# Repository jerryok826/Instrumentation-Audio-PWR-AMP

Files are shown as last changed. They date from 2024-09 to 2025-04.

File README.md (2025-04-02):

# Instrumentation-Audio-PWR-AMP

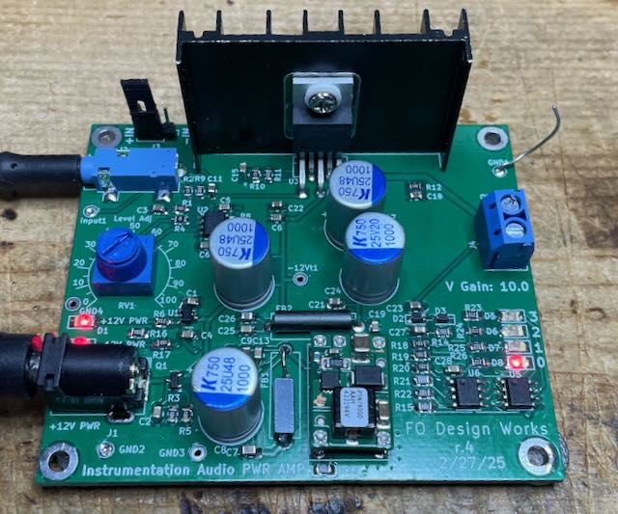
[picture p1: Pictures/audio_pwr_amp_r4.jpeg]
Robot_Front


## Project Description
I needed a audio amp I could use to test speakers and haptics. Most audio amps today seem to be class D using some form of PWM output drive. These cannot be easily be tested with a scope. So I started looking for a linear class AB audio amp. The old LM1875 meets these requirements. The other specs I was looking for were running from 12 volts. Also DC direct speaker dirve so the amp's low frequency performance was the very best.  Also I wanted a calibrated gain. With the audio attenuation pot set to 100% the input to out gain is 20. The design uses a on board 12 volt to -12v converter to generated the required negative supply voltage for the LM1875. The DC offset at the speaker terminals is typically about 1 millvolt. I call this board a "Instrumentation Audio PWR AMP" because it has known characteristicss for testing speakers and haptics. ALso the polarity of the output can be changed via a jump. Also there is a small VU meter to monitor the speaker driver level. This is mostly for debugging the a haptics test setup.

The unit should put out about 10 watts into a 4 ohm speaker. The spec sheet for the LM1875 is in the Docs directory. 

### Project Status
The project is basically complete.

## Design Files
This project was designed with Kicad 7.X

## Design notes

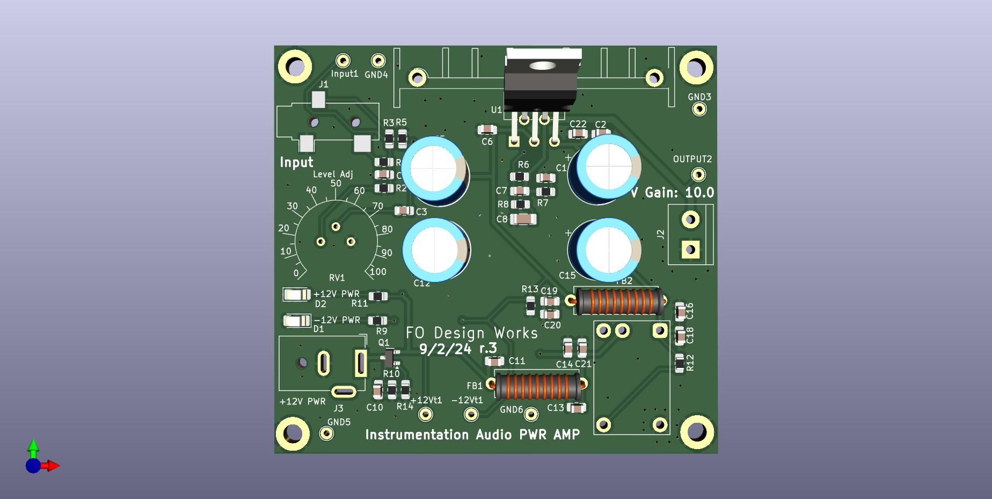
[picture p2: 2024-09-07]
Hardware/Kicad/audio_pwr_amp_r3.jpg

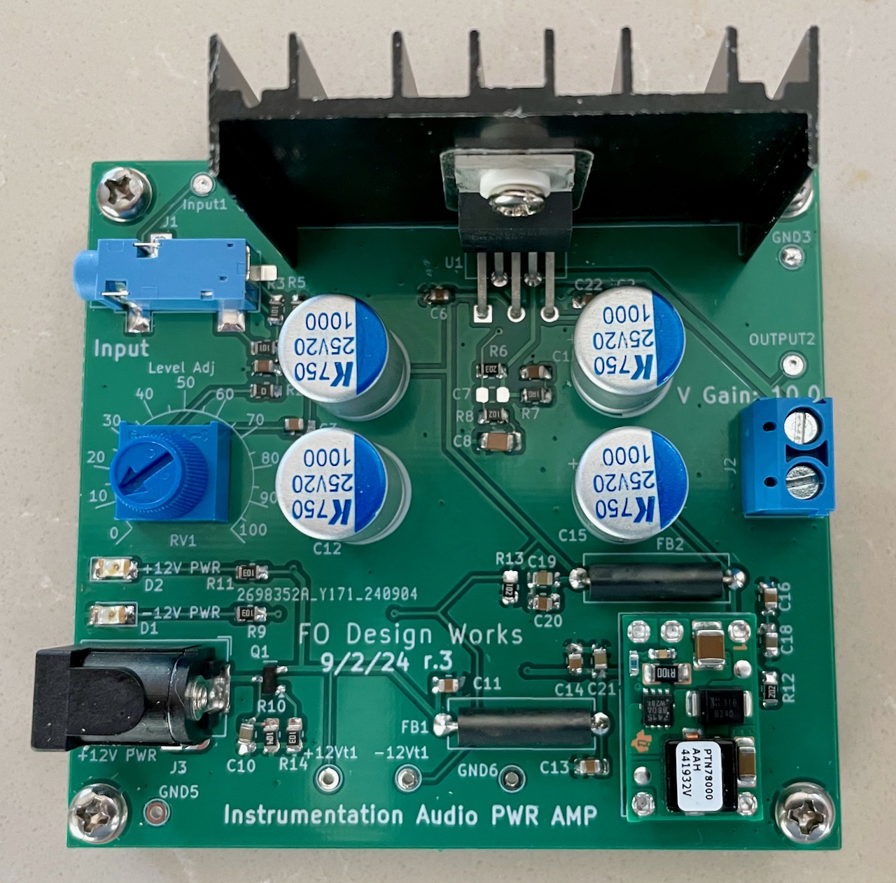
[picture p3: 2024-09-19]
Pictures/audio_pwr_amp_r3.jpeg

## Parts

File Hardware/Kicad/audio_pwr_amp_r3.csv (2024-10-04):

Source: | /home/jerryo/kicad/audio_pwr_amp/audio_pwr_amp_r3/audio_pwr_amp_r3.kicad_sch
Date: | Fri 04 Oct 2024 04:06:32 PM PDT
Tool: | Eeschema 7.0.11-7.0.11~ubuntu22.04.1
Generator: | /usr/share/kicad/plugins/bom_csv_grouped_by_value.py
Component Count: | 43
Collated Components:
Item | Qty | Reference(s) | Value | LibPart | Footprint | Datasheet | DNP | Description | Vendor | Vendor Part#
1 | 4 | C1, C5, C12, C15 | 1000uF | Device:C_Polarized_Small_US | Capacitor_THT:CP_Radial_D10.0mm_P5.00mm | ~ |  | CAP ALUM POLY 1000UF 20% 25V TH | Digikey | 399-A750MV108M1EAAE014-ND
2 | 5 | C2, C3, C6, C16, C17 | 10uF | Device:C_Small | Capacitor_SMD:C_0805_2012Metric_Pad1.18x1.45mm_HandSolder | ~ |  | CAP CER, 10uF, 25V, X7R, 0805 | Digikey | 1276-6454-1-ND
3 | 1 | C4 | 10nF | Device:C_Small | Capacitor_SMD:C_0805_2012Metric_Pad1.18x1.45mm_HandSolder | ~ |  | CAP CER, 10nF, 25V, X7R, 0805 | Digikey | 399-14402-1-ND
4 | 1 | C8 | 22uF | Device:C_Small | Capacitor_SMD:C_0805_2012Metric_Pad1.18x1.45mm_HandSolder | ~ |  | CAP CER 22UF 25V X5R 0805 | Digikey | 1276-CL21A226MAYNNNECT-ND
5 | 1 | C9 | 0.22uF | Device:C_Small | Capacitor_SMD:C_0805_2012Metric_Pad1.18x1.45mm_HandSolder | ~ |  | CAP CER, 0.22uF, 25V, X7R, 1206 | Digikey | 1276-1161-1-ND
6 | 5 | C10, C18, C19, C21, C22 | 0.1uF | Device:C_Small | Capacitor_SMD:C_0805_2012Metric_Pad1.18x1.45mm_HandSolder | ~ |  | CAP CER, 0.1uF, 25V, X7R, 0805 | Digikey | 1276-1099-1-ND
7 | 3 | C11, C13, C14 | 4.7uF | Device:C_Small | Capacitor_SMD:C_0805_2012Metric_Pad1.18x1.45mm_HandSolder | ~ |  | CAP CER, 4.7uF, 25V, X7R, 0805 | Digikey | 1276-1244-1-ND
8 | 2 | D1, D2 | RED_LED | Device:LED | LED_SMD:LED_1206_3216Metric_Pad1.42x1.75mm_HandSolder | https://sunledusa.com/products/spec/XZM2CRK55W-3.pdf |  | LED RED CLEAR SMD 1206 | Digikey | 1497-XZM2CRK55W-3RTCT-ND
9 | 2 | FB1, FB2 | FERRITE CORE SOLID 1.30MM | Device:FerriteBead_Small | Inductor_THT:L_Axial_L14.0mm_D4.5mm_P15.24mm_Horizontal_Fastron_LACC | https://www.fair-rite.com/wp-content/uploads/2019/12/2673000701cat.pdf |  | FERRITE CORE SOLID 1.30MM | Digikey | 1934-1292-ND
10 | 1 | HS1 | Heatsink_Pad_2Pin | Mechanical:Heatsink_Pad_2Pin | jerrys_Library:Heatsink_Audio_Amp | ~
11 | 1 | J1 | Audio In | audio_connector:AudioJack3 | Connector_Audio:Jack_3.5mm_CUI_SJ-3523-SMT_Horizontal |  |  | CONN JACK STEREO 3.5MM SMD R/A | Digikey | CP-3524SJBECT-ND
12 | 1 | Q1 | DMG2301L | Transistor_FET:DMG2301L | Package_TO_SOT_SMD:SOT-23 | https://www.diodes.com/assets/Datasheets/DMG2301L.pdf |  | MOSFET P-CH 20V 3A SOT23 | Digikey | DMG2301L-7DICT-ND
13 | 2 | R1, R3 | 100R | Device:R_Small_US | Resistor_SMD:R_0805_2012Metric_Pad1.20x1.40mm_HandSolder | ~ |  | RES 100 OHM 1% 1/8W 0805 | Digikey | RMCF0805FT100RCT-ND
14 | 1 | R2 | 0R | Device:R_Small_US | Resistor_SMD:R_0805_2012Metric_Pad1.20x1.40mm_HandSolder | ~ |  | RES 0 OHM JUMPER 1/8W 0805 | Digikey | 311-0.0ARCT-ND
15 | 2 | R5, R6 | 20K | Device:R_Small_US | Resistor_SMD:R_0805_2012Metric_Pad1.20x1.40mm_HandSolder | ~ |  | RES 20K OHM %1 1/10W 0805 SMD | Digikey | P20KDACT-ND
16 | 1 | R7 | 1R | Device:R_Small_US | Resistor_SMD:R_0805_2012Metric_Pad1.20x1.40mm_HandSolder | ~ |  | RES SMD 1 OHM 1% 1/2W 0805 | Digikey | 541-1.00TCT-ND
17 | 2 | R8, R13 | 1K | Device:R_Small_US | Resistor_SMD:R_0805_2012Metric_Pad1.20x1.40mm_HandSolder | ~ |  | RES 1K OHM %1 1/10W 0805 SMD | Digikey | 311-1.00KCRCT-ND
18 | 3 | R9, R11, R14 | 10K | Device:R_Small_US | Resistor_SMD:R_0805_2012Metric_Pad1.20x1.40mm_HandSolder | ~ |  | RES 10K OHM %1 1/10W 0805 SMD | Digikey | 311-10.0KCRCT-ND
19 | 1 | R10 | 100K | Device:R_Small_US | Resistor_SMD:R_0805_2012Metric_Pad1.20x1.40mm_HandSolder | ~ |  | RES 100K OHM 1% 1/8W 0805 | Digikey | 311-100KCRCT-ND
20 | 1 | R12 | 2K | Device:R_Small_US | Resistor_SMD:R_0805_2012Metric_Pad1.20x1.40mm_HandSolder | ~ |  | RES SMD 2K OHM 1% 1/8W 0805 | Digikey | P2.00KCCT-ND
21 | 1 | RV1 | 1k | Device:R_Potentiometer_US | jerrys_Library:Potentiometer_Bourns_3386P_Vertical | https://www.bourns.com/docs/Product-Datasheets/3386.pdf |  | TRIMMER 1K OHM 0.5W PC PIN TOP | Digikey | 3386F-1-102TLF-ND
22 | 1 | U1 | LM1875 | Amplifier_Audio:LM1875 | Package_TO_SOT_THT:TO-220-5_P3.4x3.7mm_StaggerOdd_Lead3.8mm_Vertical | http://www.ti.com/lit/ds/symlink/lm1875.pdf |  | IC AMP CLASS AB MONO 25W TO220-5 | Digikey | LM1875T/NOPB-ND
23 | 1 | U2 | PTN78000AAH | jerrys_Library:PTN78000A | Module:Texas_EUS_R-PDSS-T5_THT | https://www.ti.com/lit/ds/symlink/ptn78000a.pdf |  | DC DC CONVERTER -15 TO -3V | Digikey | 296-20501-ND

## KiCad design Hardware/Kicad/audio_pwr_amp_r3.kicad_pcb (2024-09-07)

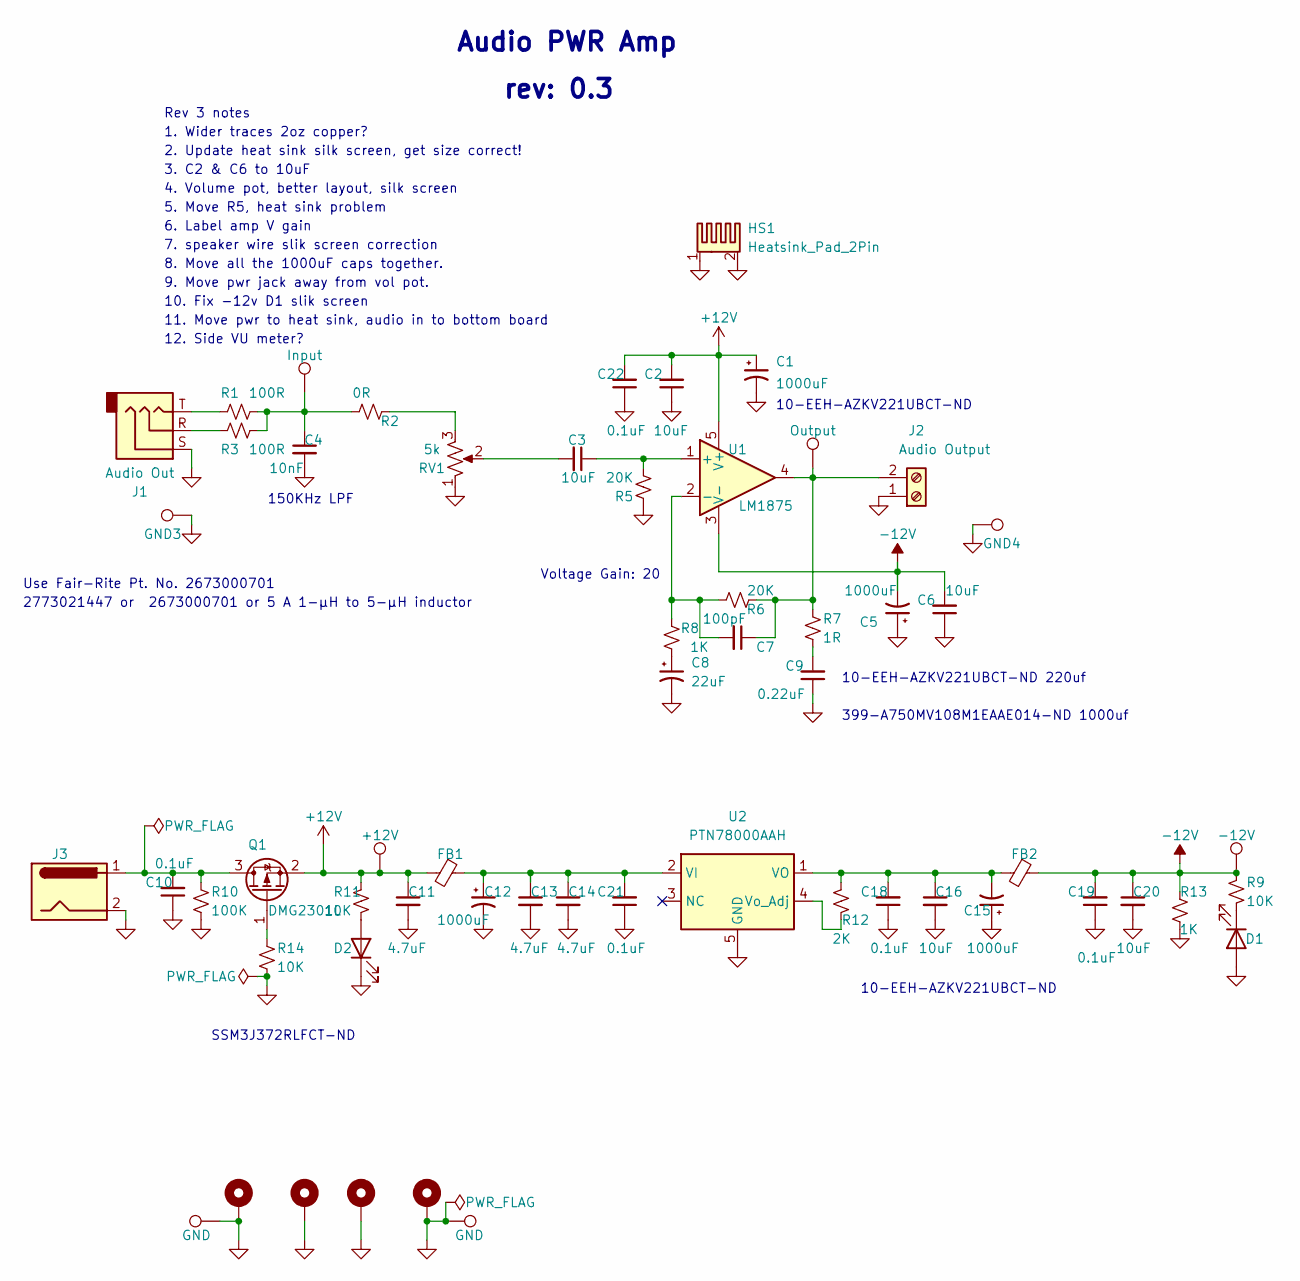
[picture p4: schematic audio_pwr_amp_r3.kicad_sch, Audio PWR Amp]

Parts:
+12Vt1: +12V; TestPoint_THTPad_D2.0mm_Drill1.0mm
-12Vt1: -12V; TestPoint_THTPad_D2.0mm_Drill1.0mm
C1, C5, C12, C15: 1000uF; CP_Radial_D10.0mm_P5.00mm
C2, C3, C6, C16, C20: 10uF; C_0805_2012Metric_Pad1.18x1.45mm_HandSolder
C4: 10nF; C_0805_2012Metric_Pad1.18x1.45mm_HandSolder
C7: 100pF; C_0805_2012Metric_Pad1.18x1.45mm_HandSolder
C8: 22uF; C_1206_3216Metric_Pad1.33x1.80mm_HandSolder
C9: 0.22uF; C_0805_2012Metric_Pad1.18x1.45mm_HandSolder
C10, C18, C19, C21, C22: 0.1uF; C_0805_2012Metric_Pad1.18x1.45mm_HandSolder
C11, C13, C14: 4.7uF; C_0805_2012Metric_Pad1.18x1.45mm_HandSolder
D1, D2: OC_Fault; LED_1206_3216Metric_Pad1.42x1.75mm_HandSolder
FB1, FB2: FerriteBead, 6A 1 9mΩ 33Ω@100MHz ±25% 1206 Ferrit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; L_Axial_L14.0mm_D4.5mm_P15.24mm_Horizontal_Fastron_LACC
GND3, GND4: TP_FET_Drive; TestPoint_THTPad_D2.0mm_Drill1.0mm
GND5, GND6: GND; TestPoint_THTPad_D2.0mm_Drill1.0mm
H1, H2, H3, H4: MountingHole_Pad; MountingHole_3.2mm_M3_ISO7380_Pad_TopBottom
HS1: Heatsink_Pad_2Pin; Heatsink_Audio_Amp
Input1: Input; TestPoint_THTPad_D2.0mm_Drill1.0mm
J1: Audio Out; Jack_3.5mm_CUI_SJ-3523-SMT_Horizontal
J2: Audio Output; TerminalBlock_bornier-2_P5.08mm; LCSC No Stock
J3: INPUT_PWR; BarrelJack_GCT_DCJ200-10-A_Horizontal
OUTPUT2: Output; TestPoint_THTPad_D2.0mm_Drill1.0mm
Q1: DMG2301L; SOT-23
R1, R3: 100R; R_0805_2012Metric_Pad1.20x1.40mm_HandSolder
R2: 0R; R_0805_2012Metric_Pad1.20x1.40mm_HandSolder
R5, R6: 20K; R_0805_2012Metric_Pad1.20x1.40mm_HandSolder
R7: 1R; R_0805_2012Metric_Pad1.20x1.40mm_HandSolder
R8, R13: 1K; R_0805_2012Metric_Pad1.20x1.40mm_HandSolder
R9, R11, R14: 10K; R_0805_2012Metric_Pad1.20x1.40mm_HandSolder
R10: 100K; R_0805_2012Metric_Pad1.20x1.40mm_HandSolder
R12: 2K; R_0805_2012Metric_Pad1.20x1.40mm_HandSolder
RV1: 5k; Potentiometer_Bourns_3386P_Vertical
U1: LM1875; TO-220-5_P3.4x3.7mm_StaggerOdd_Lead3.8mm_Vertical
U2: PTN78000AAH; Texas_EUS_R-PDSS-T5_THT

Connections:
+12V: +12Vt1.1, C1.1, C2.2, C11.1, C22.2, FB1.2, Q1.2 (S), R11.2, U1.5 (V+)
-12V: -12Vt1.1, C5.2, C6.2, C19.2, C20.1, FB2.1, R9.2, R13.2, U1.3 (V-)
GND: C1.2, C2.1, C4.2, C5.1, C6.1, C8.2, C9.1, C10.1, C11.2, C12.2, C13.2, C14.2, C15.1, C16.2, C18.1, C19.1, C20.2, C21.1, C22.1, D1.2 (A), D2.1 (K), GND3.1, GND4.1, GND5.1, GND6.1, H1.1, H2.1, H3.1, H4.1, HS1.1, HS1.2, J1.S, J2.1, J3.2, R5.1, R10.2, R13.1, R14.2, RV1.1, U2.5 (GND)
unnamed: C3.2, RV1.2
unnamed: C4.1, Input1.1, R1.1, R2.2, R3.1
unnamed: C8.1, R8.1
unnamed: C9.2, R7.2
unnamed: D1.1 (K), R9.1
unnamed: D2.2 (A), R11.1
unnamed: J1.R, R3.2
unnamed: J1.T, R1.2
unnamed: C7.1, J2.2, OUTPUT2.1, R6.2, R7.1, U1.4
unnamed: C10.2, J3.1, Q1.3 (D), R10.1
unnamed: Q1.1 (G), R14.1
unnamed: R2.1, RV1.3
unnamed: C3.1, R5.2, U1.1 (+)
unnamed: C7.2, R6.1, R8.2, U1.2 (-)
unnamed: C12.1, C13.1, C14.1, C21.2, FB1.1, U2.2 (VI)
unnamed: C15.2, C16.1, C18.2, FB2.2, R12.2, U2.1 (VO)
unnamed: R12.1, U2.4 (Vo_Adj)

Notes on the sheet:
399-A750MV108M1EAAE014-ND 1000uf
5. Move R5, heat sink problem
4. Volume pot, better layout, silk screen
10-EEH-AZKV221UBCT-ND 220uf
rev: 0.3
9. Move pwr jack away from vol pot.
2773021447 or 2673000701 or 5 A 1-μH to 5-μH inductor
8. Move all the 1000uF caps together.
3. C2 & C6 to 10uF
6. Label amp V gain
Audio PWR Amp
7. speaker wire slik screen correction
11. Move pwr to heat sink, audio in to bottom board
Voltage Gain: 20
10-EEH-AZKV221UBCT-ND
150KHz LPF
12. Side VU meter?
SSM3J372RLFCT-ND
2. Update heat sink silk screen, get size correct!
10. Fix -12v D1 slik screen
Rev 3 notes
Use Fair-Rite Pt. No. 2673000701
1. Wider traces 2oz copper?

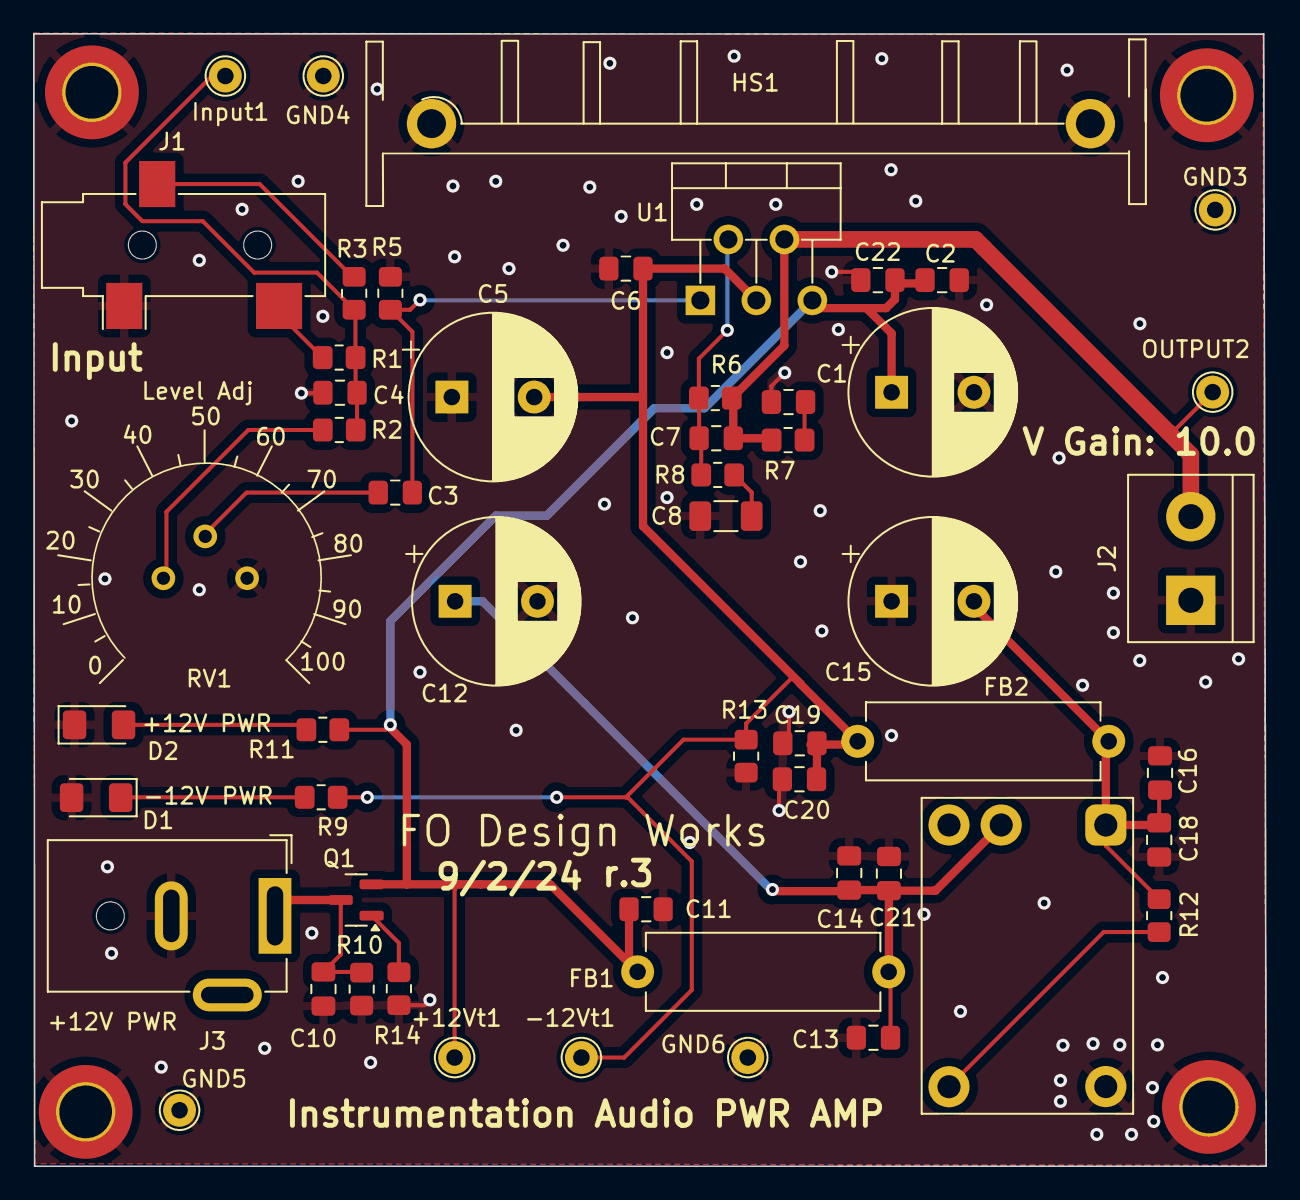
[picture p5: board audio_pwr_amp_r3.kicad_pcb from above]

Board: 2 copper layers, 74.8 x 68.8 mm, 58 parts (0 on the bottom side), 20 nets.
